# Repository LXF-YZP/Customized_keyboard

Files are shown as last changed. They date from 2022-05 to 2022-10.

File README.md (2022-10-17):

### GPL3协议
### 项目所有文件禁止商用，旨在进行客制化键盘的交流与分享；

## 键盘简单说明

键盘主控使用的是atmega32u4-mu，这里解释一下为什么使用这个芯片，因为最开始画pcb的只会画32u4-au和32u4-mu，其中32u4-mu便宜所以选的这个。
至于更便宜的apm32芯片，仿照的stm32芯片画了一个apm32的pcb图，用于制作pad，刚打样还没有制作完成。对于小配列的键盘也可以使用32u2芯片，比如hhkb或者pad都是可以的，因为32U2相对与32u4便宜；
客制化键盘制作，pcb单模无灯，外壳树脂打印。

更新完qmk固件之后，支持 VIA 实时改键，全键无冲。

+ 目前40配列和hhkb兼容配列的固件还没有编写,pcb也还没有验证,建议等我验证之后再使用；

## 项目分支
>+ master分支： 该分支是田字68的键盘数据。
>+ alice分支：  该分支是Alice配列键盘数据。
>+ hhkb分支：该分支是hhkb配列键盘数据。  
>+ forty_arrangement分支：该分支是40配列键盘数据。  
>+ keypad_frame分支： 键盘支架。 
>+ pad分支： 数字小键盘配列数据。 
>+ seventy_three_arrangement：该分支为73配列键盘数据。
>+ sixty_eight_vim：该分支是68配列键盘数据。（方向键在最下面一排）  

## 目录结构：  
>+ bom 元器件表  
>+ case 外壳图纸  
>+ config 固件文件,支持via改键，解压kafka.zip之后，直接放到qmk的keyboards目录下就可以编译生成hex文件，或者直接使用文件夹中的hex文件  
>+ gerber 制作pcb要上传到立创的压缩文件  
>+ location_plate 配列文件  
>+ pcb pcb原理图  
>+ photo 键盘渲染图，实物图  
>+ screw 螺丝  
>+ acrylic_shell 亚克力外壳图纸

## PCB说明
>>田字68pcb文件中只有无灯无开槽的是适配了3D打印外壳的；田字68的其他pcb还没有适配外壳，其实适配外壳也很简单，无灯的pcb直接修改一下外壳的type-c口即可，有灯的pcb需要在方向键上方开一个适当大小的铭牌口即可。最后解释一下为什么田字68要画这么多pcb的原因，有以下几个原因，pcb开槽和不开槽在手感上有很大差别的，开槽的会更加软弹，不开槽的手感会偏硬一点，gasket结构配上开槽pcb会更加软弹，至于pcb横开槽和全开槽在手感方面也有一点区别，所以制作了多个pcb，本人对轴灯无感，一是光污染（尤其晚上关灯之后），二是画pcb电路图很麻烦（画过一次再也不想画了，玩亚克力的可能会喜欢轴灯），但是本人对氛围灯很有好感，所以有开槽的pcb都有氛围灯。

## 配列图

##### 68配列
+ master分支的68配列如下图所示：
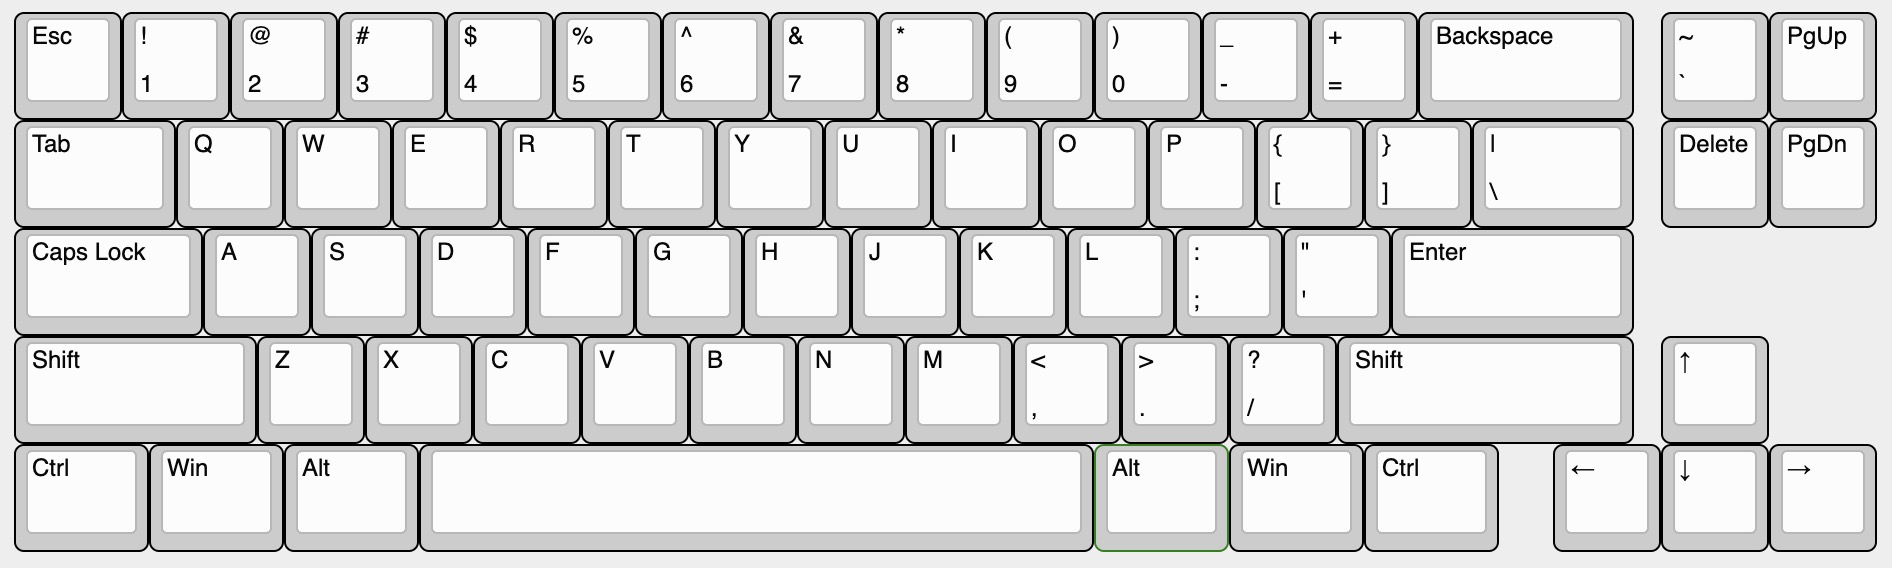
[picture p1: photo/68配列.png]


+ 下列68配列为个人的一些改动：
该配列的配套pcb和外壳还未画好，不过后期都会更新好；
七月三十号pcb外壳已更新，亚克力外壳的准备文件也已更新，亚克力外壳就不再画完整的了，可以在我更新的准备文件基础上进行修改。现在只有固件是没有更新了。如果后续我单板的话，回去更新固件，或者你单板了，可以找我要固件；
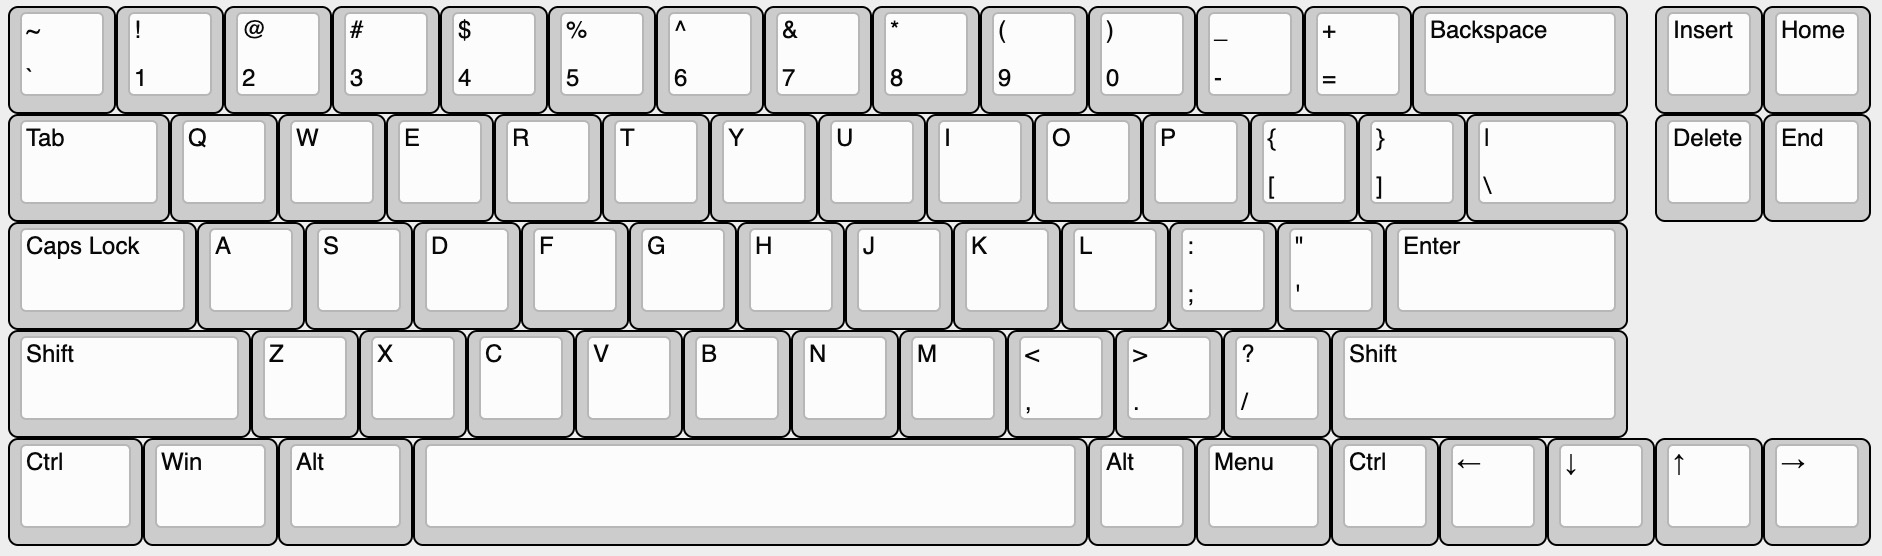
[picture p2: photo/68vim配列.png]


##### hhkb配列
+ hhkb分支的配列如下图：
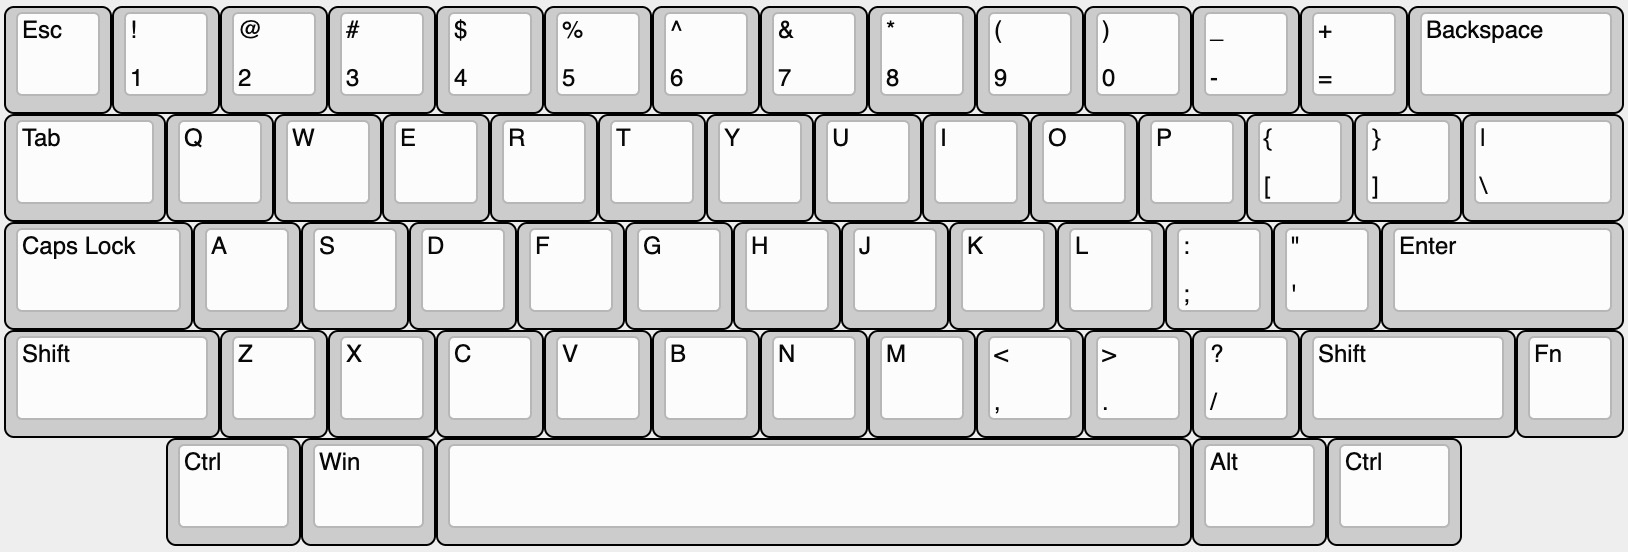
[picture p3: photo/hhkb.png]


+ 下列类hhkb配列为个人的一些改动：
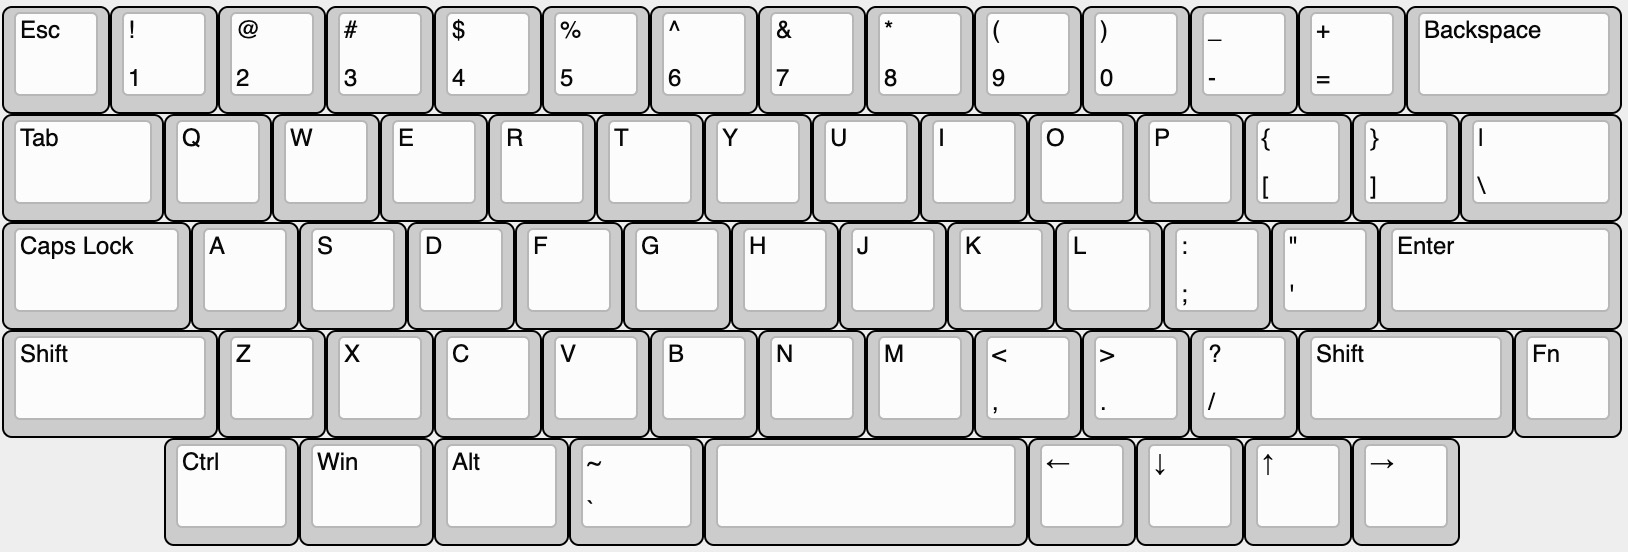
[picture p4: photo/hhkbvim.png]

>> 以上两个配列共用一套pcb和外壳而且已经画好上传到相关文件夹中；pcb是包含两个pcb的gerber文件的，一个是未开槽的pcb只是类hhkb配列的；一个是已经开槽的pcb，这个pcb就是上面说的兼容两个配列的pcb，而且是分离小板的；

##### Alice配列
+ 下面配列是Alice配列：
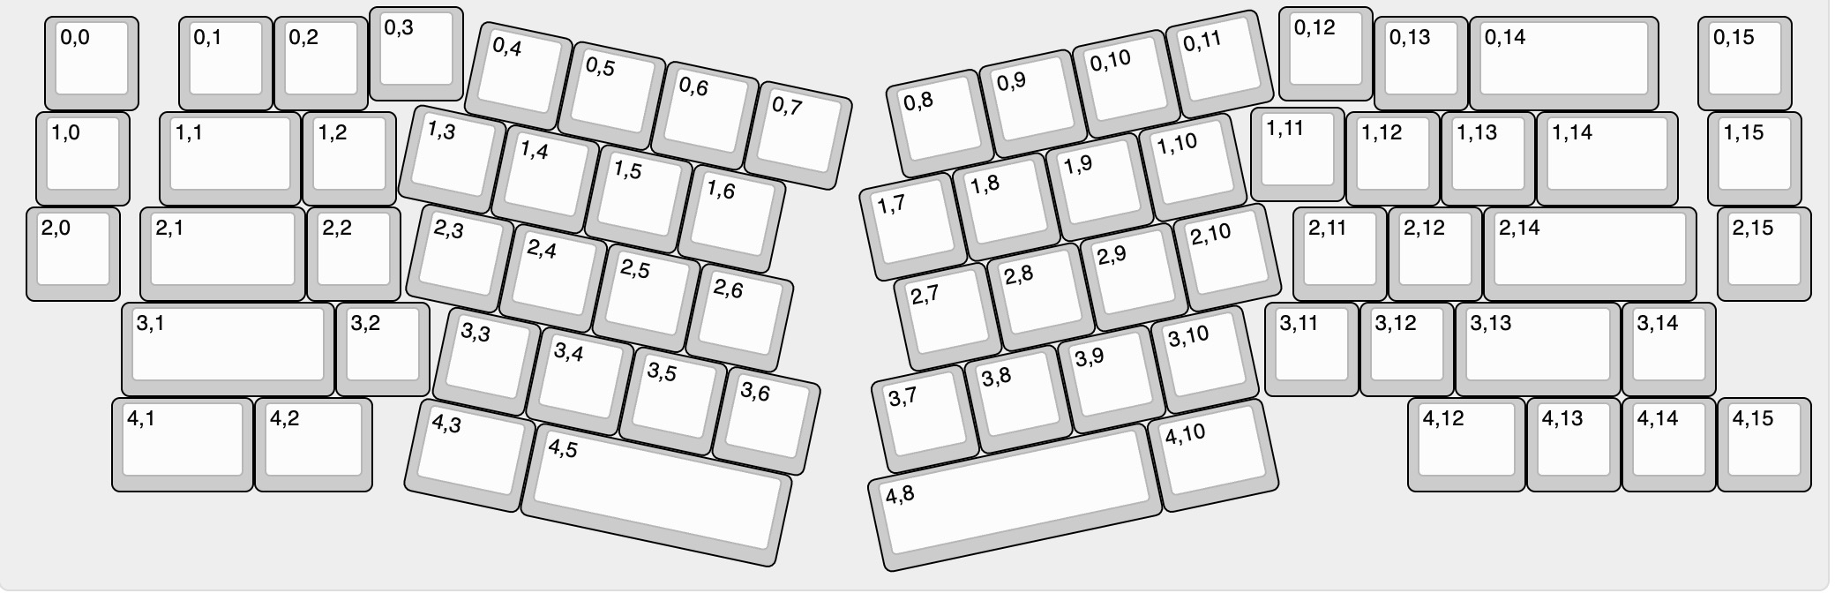
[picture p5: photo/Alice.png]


##### 40配列

+ 40配列如下图
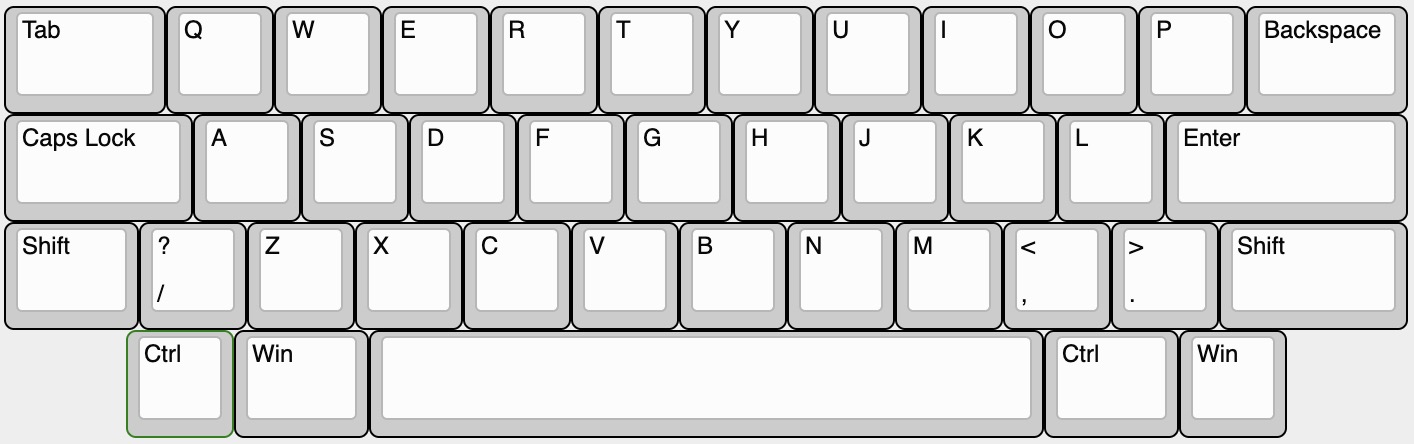
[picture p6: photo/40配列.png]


+ 下列40配列为个人的一些改动：
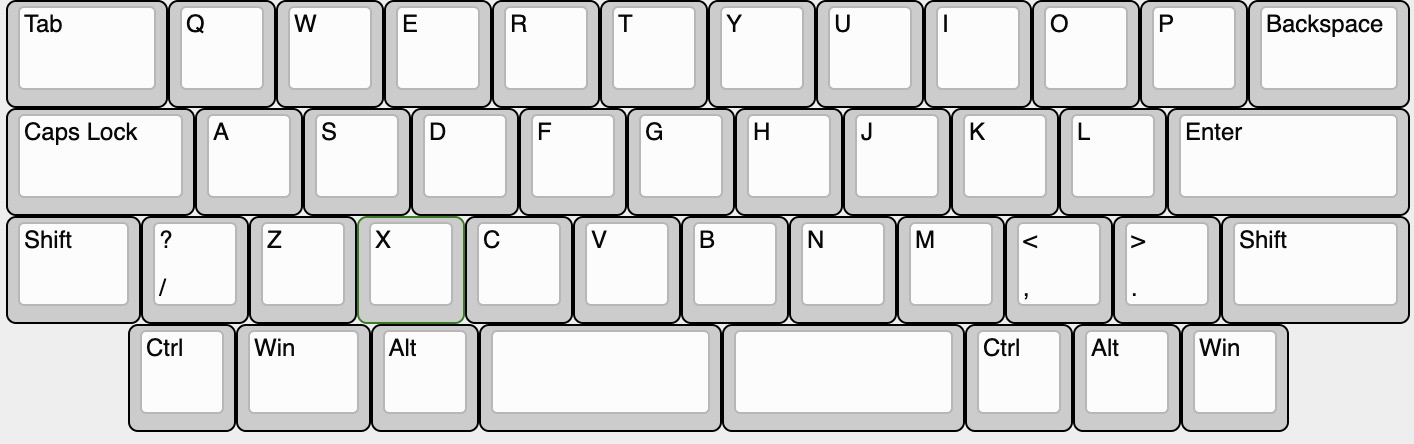
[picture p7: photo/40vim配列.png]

>> 以上两个配列共用一套pcb和外壳而且已经画好上传到相关文件夹中；

##### 73配列

+ 这里多说两句，这个配列最初是在B站看到别人发的一个pcb动态，第一眼感觉很惊艳，所以就自己设计了一款，设计的初衷是送一个朋友的，所以pcb设计的时候走线规整了很多，看着还是比较好看的，由于自己打板子的时候没有选择沉金，所以走线得仔细看才能看出好不好看，要是用沉金的话，就可以把走线都体现出来了，奈何沉金太贵了，要是开团的话选沉金还是不错的。pcb不会开源，该配列主要送朋友的；

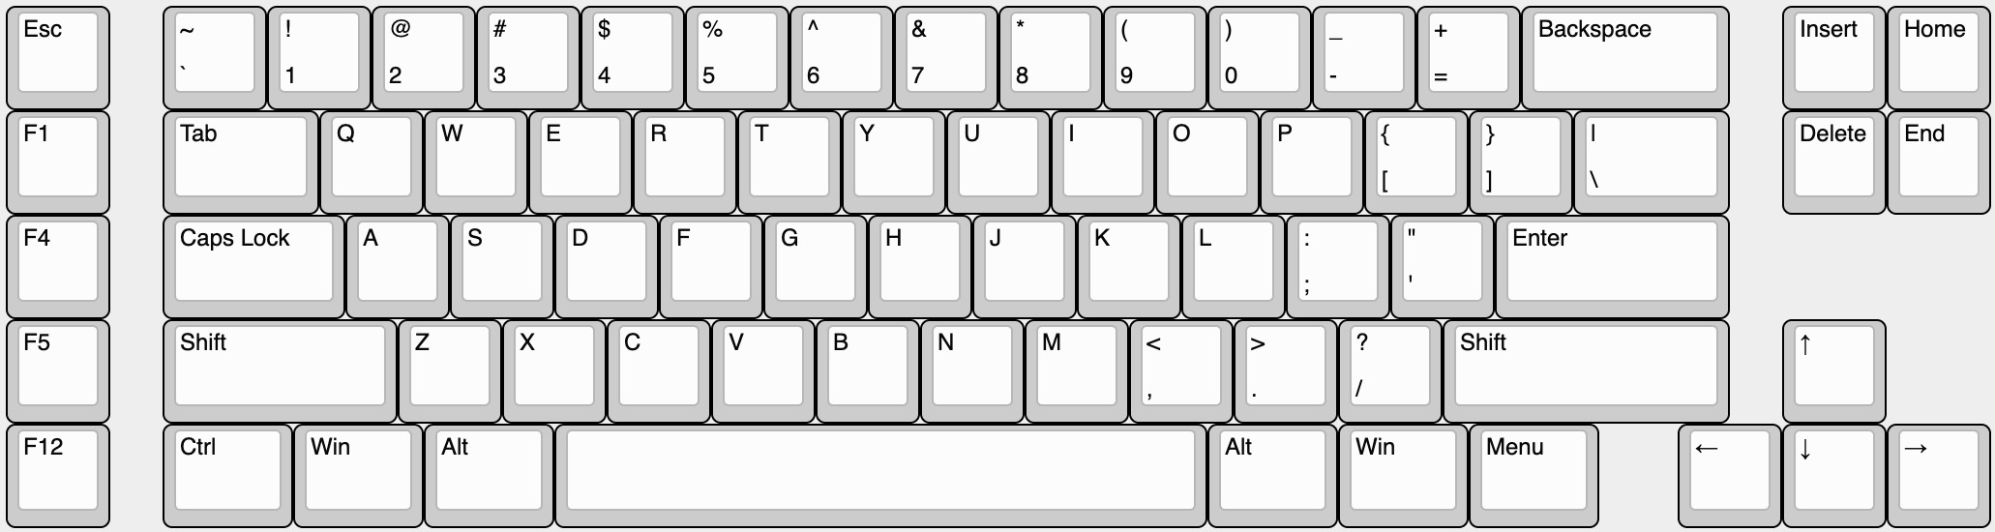
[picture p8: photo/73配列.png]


>> 这个配列开源的pcb和外壳还有固件都是自己最初设计的一版，但是外壳不会开源，因为送朋友的外壳有很多是她自己喜欢的一些元素，所以不开源外壳。但是我有时间会再设计一款外壳。73配列带底灯版本外壳已更新，相关文件后缀带有底灯字样。

田字68全开槽不带分离小板的外壳已经更新，在case文件夹里面的case/田字68底壳.stl文件，其他部分的stl文件是通用的；固件在config/tiankafka_via.hex, via文件在config/tian_kafka_via.json

##### pad

+ pad如下图

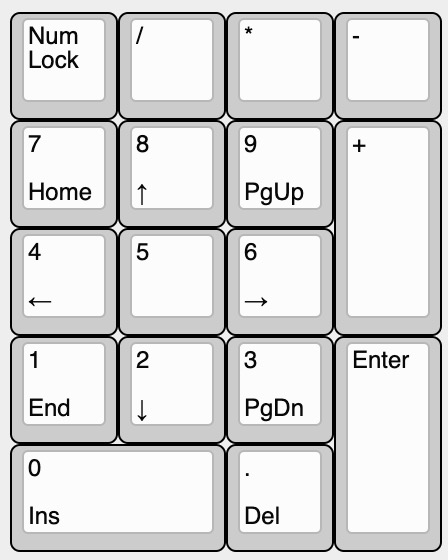
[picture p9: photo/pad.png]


pad使用的芯片为stm32f103,可以使用apm替代，该pad为了验证芯片电路图是否使用正确所画，当前状态为未打板，建议等我打板验证之后再使用。

##### 75配列

+ 75配列如下图

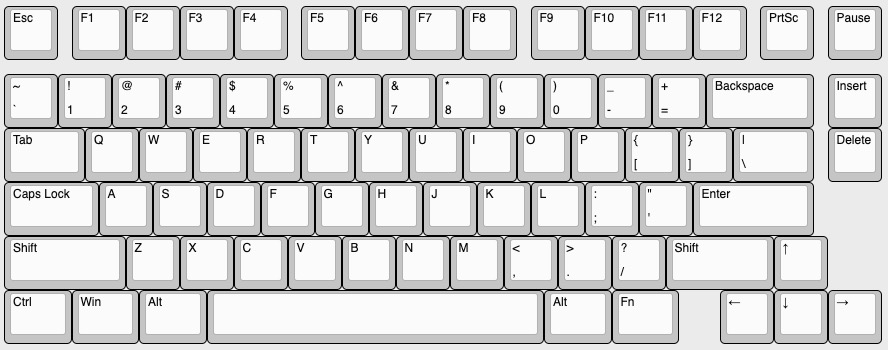
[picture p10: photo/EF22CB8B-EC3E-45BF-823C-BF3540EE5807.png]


75配列使用的芯片为stm32f103,可以使用apm替代，当前pcb还未打板验证，亚克力外壳还没制作，3D打印外壳也还未制作。

+ 79配列如下图

![image]()
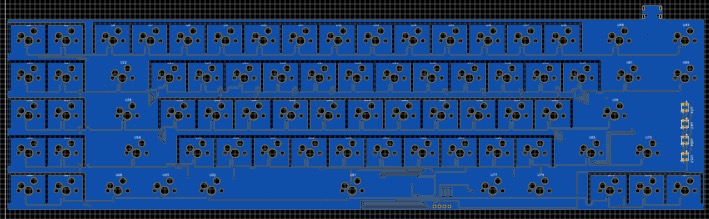
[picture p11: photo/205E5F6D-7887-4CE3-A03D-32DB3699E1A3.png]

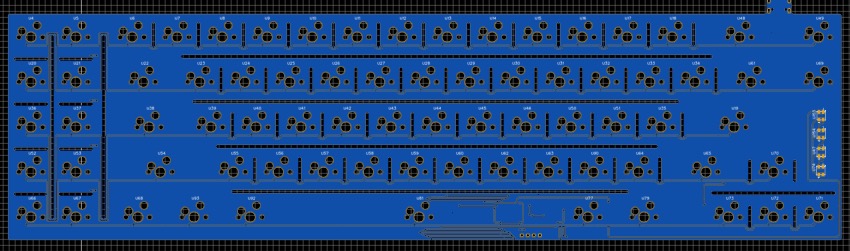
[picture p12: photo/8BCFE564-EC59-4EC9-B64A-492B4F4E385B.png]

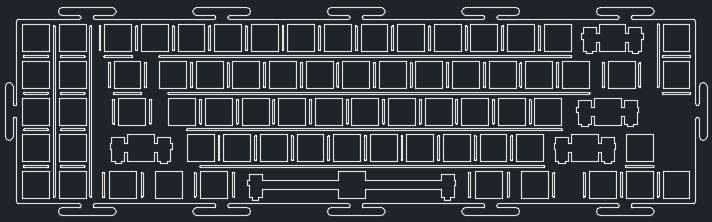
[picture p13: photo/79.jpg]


79配列使用的芯片为stm32f103,可以使用apm替代，pcb有全开槽也有横开槽，当前pcb还未打板验证，亚克力外壳还没制作，3D打印外壳也还未制作。

## 其他配列的pcb图纸有时间再上传吧，其他配列的pcb也有横开槽和全开槽的，部分pcb有竖开槽的。

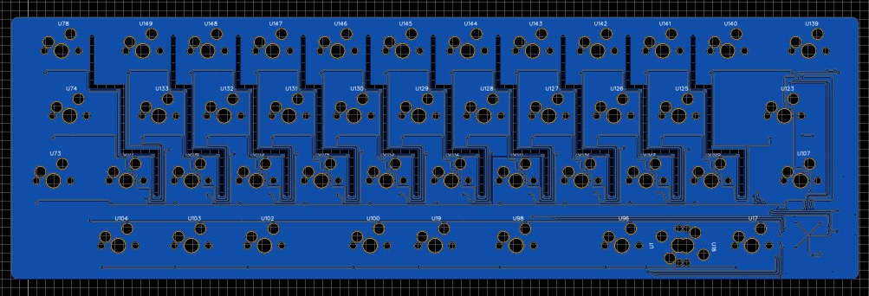
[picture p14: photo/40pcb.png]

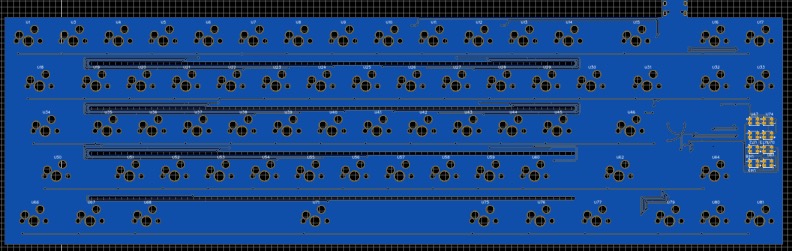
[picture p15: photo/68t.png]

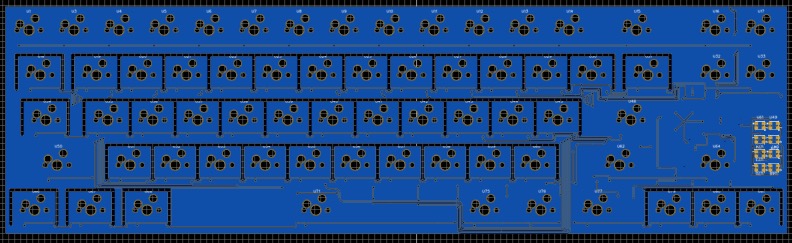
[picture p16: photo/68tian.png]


暂时未适配外壳

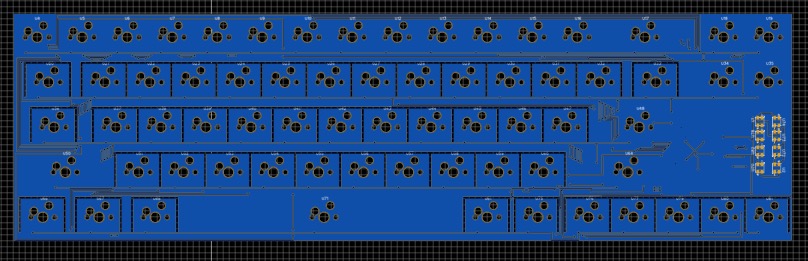
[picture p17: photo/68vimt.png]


暂时未适配外壳

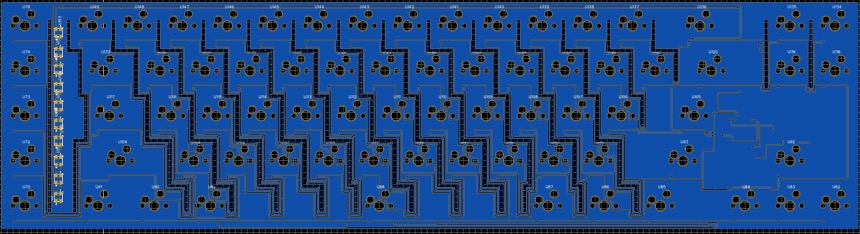
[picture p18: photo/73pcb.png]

该73配列pcb不会开源；

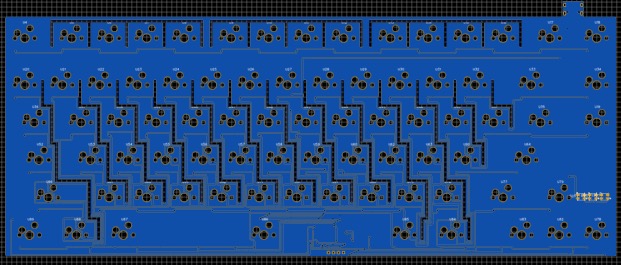
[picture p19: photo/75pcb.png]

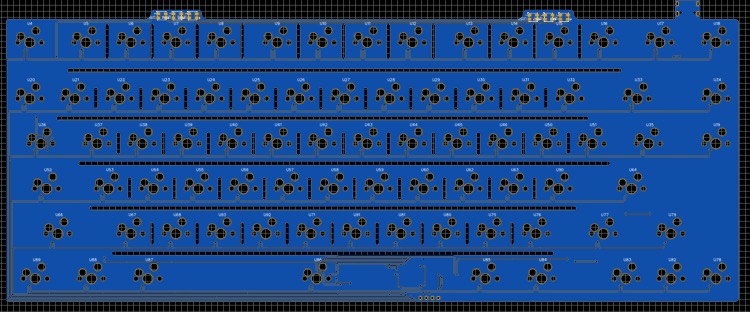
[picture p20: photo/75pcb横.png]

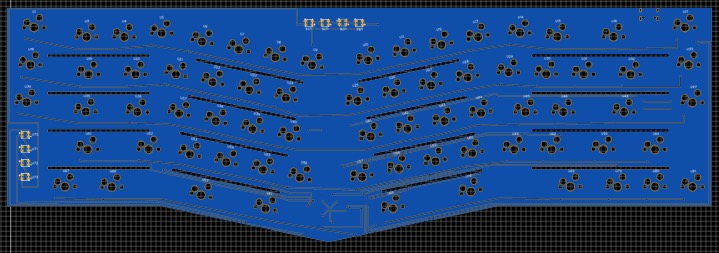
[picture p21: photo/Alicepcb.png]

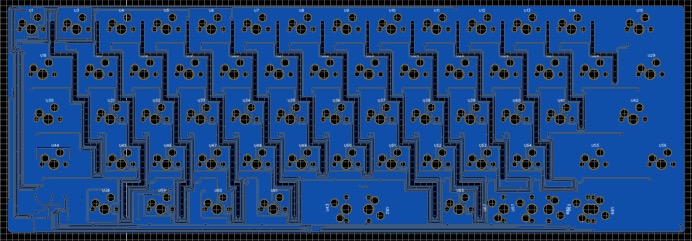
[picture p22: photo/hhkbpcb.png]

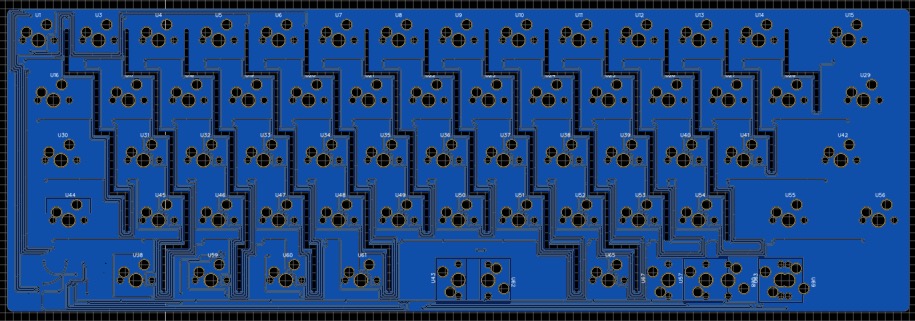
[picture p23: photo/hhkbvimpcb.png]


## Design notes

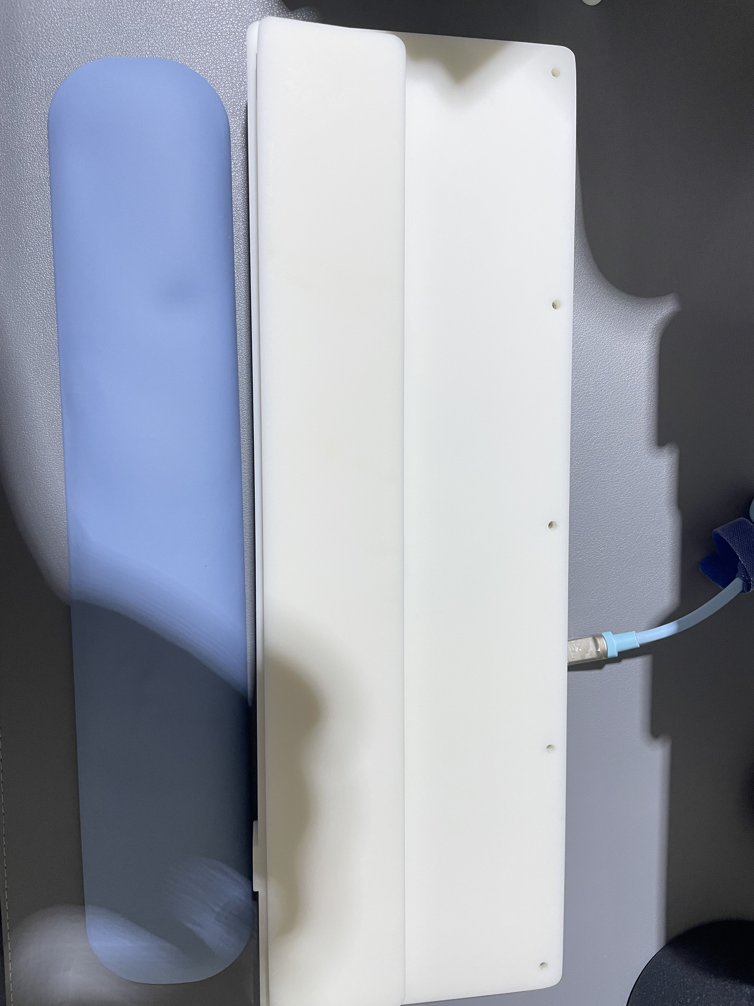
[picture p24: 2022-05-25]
photo/DBA4A1ACDF9258B40D42B9F581A96AAB.png

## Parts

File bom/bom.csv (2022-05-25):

ID | Name | Designator | Footprint | Quantity | Manufacturer Part | Manufacturer | Supplier | Supplier Part | Price | 3DModel
1 | 20pF | C1,C2 | C0805 | 2 | VJ0805D200JLAAJ | VISHAY(威世) | LCSC | C2310327 | 1.3843 | C0805_L2.0-W1.3-H1.3
2 | 1uF | C3 | C0805 | 1 | CL21B105KBFNNNE | SAMSUNG | LCSC | C28323 | 0.0537 | C0805_L2.0-W1.3-H1.3
3 | 100nF | C4,C5,C6,C7 | C0805 | 4 | 0805B104J500NT | FH | LCSC | C29926 | 0.0694 | C0805_L2.0-W1.3-H1.3
4 | 470nF | C8 | C0805 | 1 | 0805B474K500NT | FH | LCSC | C49955 | 0.1168 | C0805_L2.0-W1.3-H1.3
5 | Switch3x4x2 | KEY3 | SW-SMD_L4.0-W2.9-LS5.0 | 1 | Switch3x4x2 | ReliaPro | LCSC | C26638 | 0.2557 | SW-SMD_L4.0-W2.9-H2-LS5.0
6 | 22 | R4,R6 | R0805 | 2 | RC0805FR-0722RL | YAGEO | LCSC | C107702 | 0.0159 | R0805_L2.0-W1.3-H0.6
7 | 10K | R9,R10 | R0805 | 2 | RC0805FR-0710KL | YAGEO | LCSC | C84376 | 0.0154 | R0805_L2.0-W1.3-H0.6
8 | ATMEGA32U4-MU | U2 | VQFN-44_L7.0-W7.0-P0.50-BL-EP5.2 | 1 | ATMEGA32U4-MU | MICROCHIP | LCSC | C112161 | 71.43 | VQFN-44_L7.0-W7.0-H1.0-P0.50
9 | TYPE-C-31-M-12 | USBC2 | USB-C_SMD-TYPE-C-31-M-12 | 1 | TYPE-C-31-M-12 | Rectangular Connectors - Contacts | LCSC | C165948 | 1.5165 | USB-C_SMD-TYPE-C-31-M-12
10 | 16MHz | X3 | OSC-SMD_2P-L5.0-W3.2 | 1 | XSHEELNANF-16MHZ | TAITIEN Elec | LCSC | C242221 | 2.39 | OSC-SMD-2P_L5.0-W3.2-H1.4
11 | 1N4148W T4 | D1,D2,D3,D4,D5,D6,D7,D8,D9,D10,D11,D12,D13,D14,D15,D16,D17,D18,D19,D20,D21,D22,D23,D24,D25,D26,D27,D28,D29,D30,D31,D32,D33,D34,D35,D36,D37,D38,D39,D40,D41,D42,D43,D44,D45,D49,D50,D51,D52,D53,D54,D55,D56,D57,D58,D59,D61,D63,D65,D66,D67,D70,D74,D75,D76,D78,D79,D80 | SOD-123_L2.8-W1.8-LS3.7-RD | 68 | 1N4148W T4 | CJ | LCSC | C2099 | 0.0844 | SOD-123_L2.8-W1.8-LS3.7-RD
12 | 两用轴座无灯 | U1,U3,U4,U5,U6,U7,U8,U9,U10,U11,U12,U13,U14,U15,U16,U17,U18,U19,U20,U21,U22,U23,U24,U25,U26,U27,U28,U29,U30,U31,U32,U33,U34,U35,U36,U37,U38,U39,U40,U41,U42,U43,U44,U45,U46,U50,U51,U52,U53,U54,U55,U56,U57,U58,U59,U60,U62,U64,U66,U67,U68,U71,U75,U76,U77,U79,U80,U81 | 两用轴座无灯 | 68

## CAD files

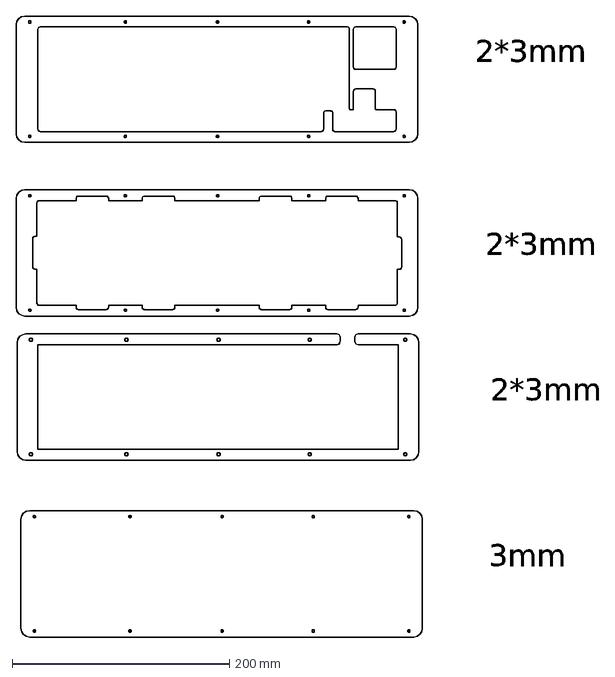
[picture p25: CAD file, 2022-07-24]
acrylic_shell/亚克力外壳.dxf
2*3mm
3mm

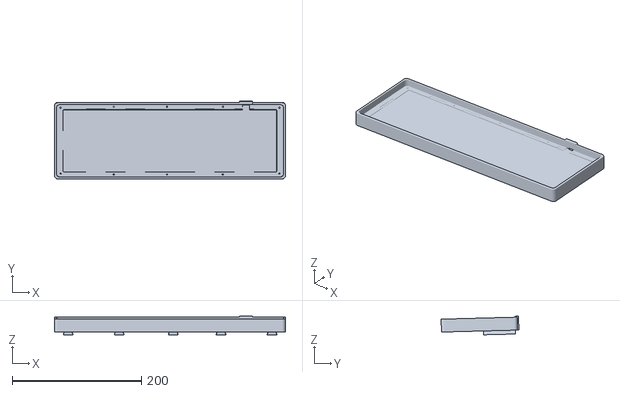
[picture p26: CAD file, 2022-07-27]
case/田字68底壳.stl
357.6 x 120.5 x 28.9

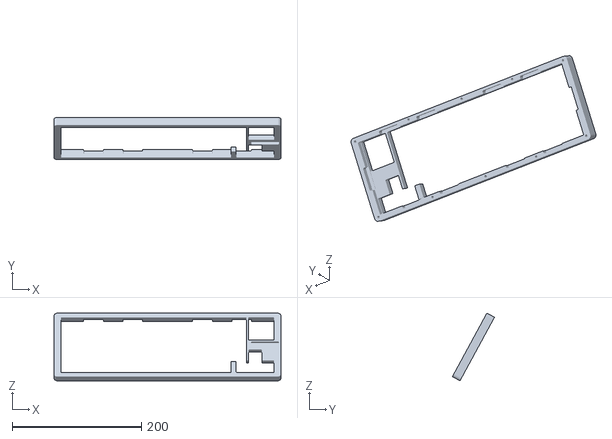
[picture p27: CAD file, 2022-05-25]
case/上壳.stl
351.6 x 65.1 x 104.7

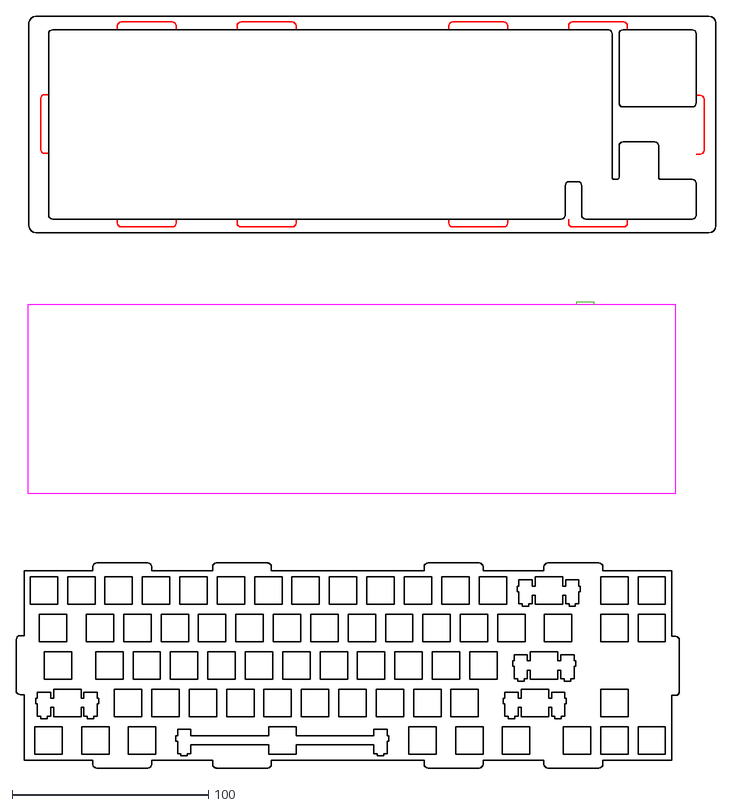
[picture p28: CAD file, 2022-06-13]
location_plate/定位板.dxf
356.3 x 383.0

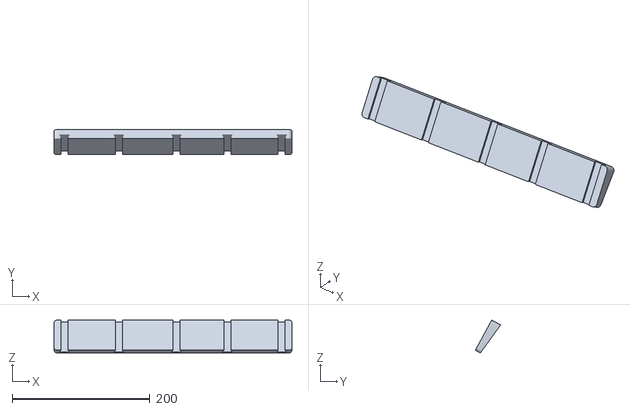
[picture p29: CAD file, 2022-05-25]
case/配重.stl
346.0 x 36.9 x 48.0

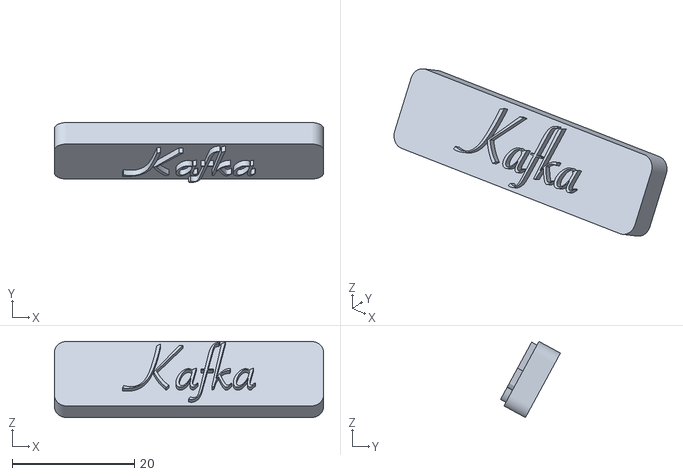
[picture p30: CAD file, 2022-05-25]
case/铭牌.stl
44.0 x 9.80 x 12.5

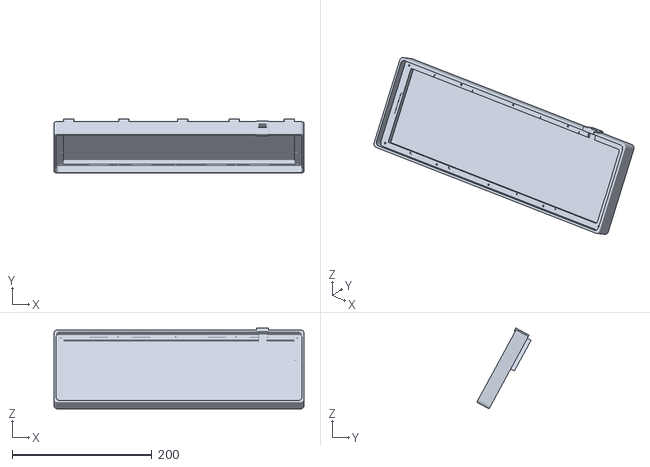
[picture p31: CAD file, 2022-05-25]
case/底壳.stl
357.6 x 77.5 x 115.5

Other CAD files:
location_plate/定位板基板.dwg

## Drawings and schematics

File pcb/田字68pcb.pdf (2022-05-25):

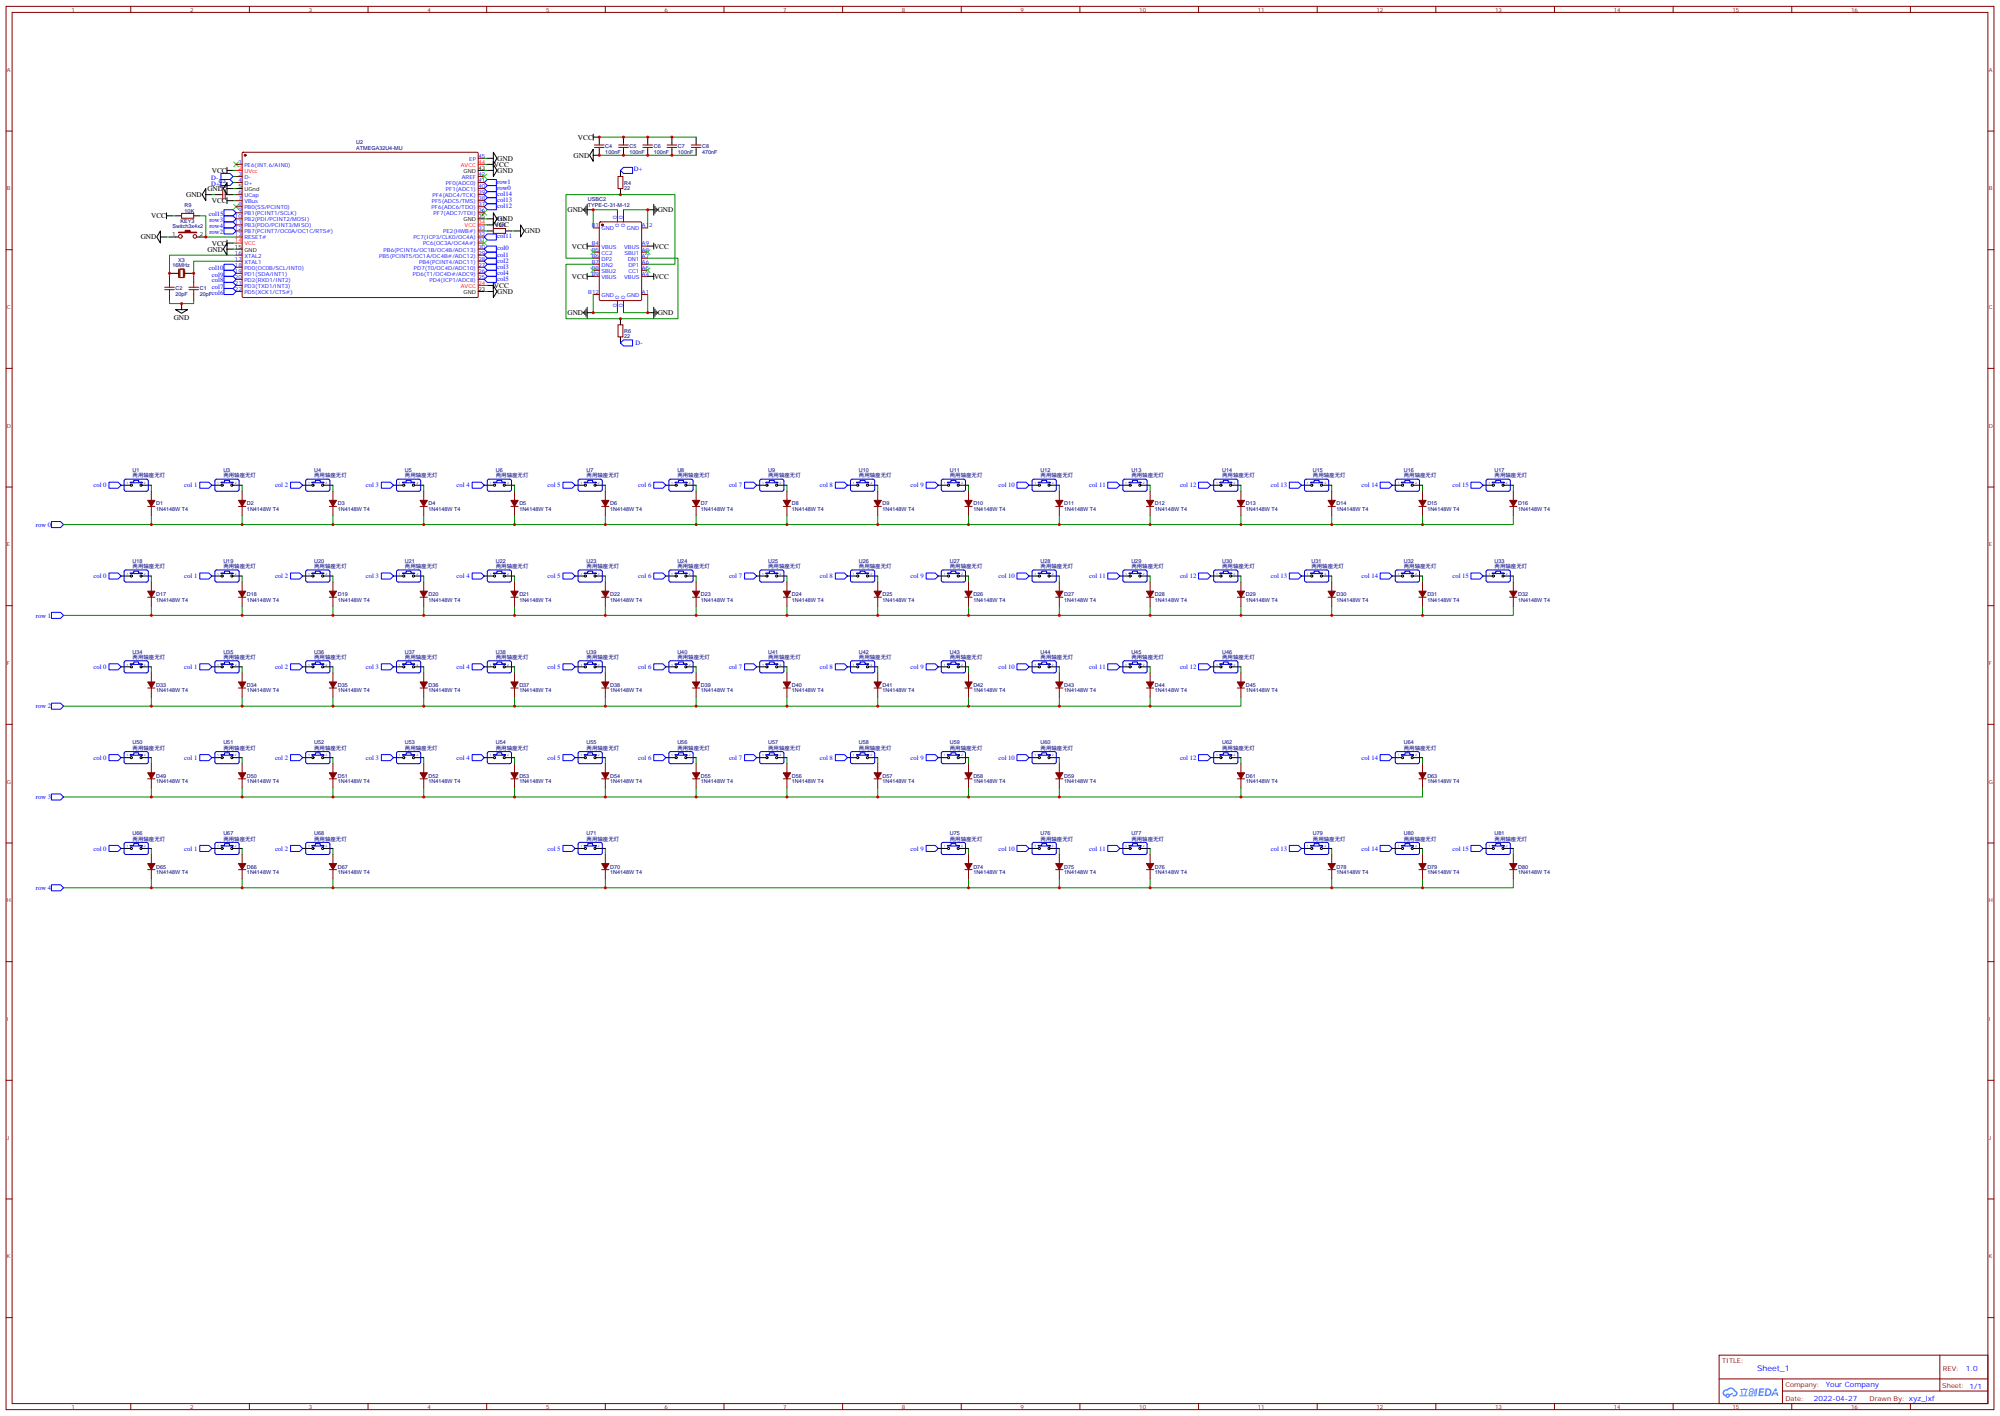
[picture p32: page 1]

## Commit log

2022-05-25 客制化键盘
2022-05-25 删除.un后缀文件
2022-05-25 添加必要文件
    [bom.csv, 上壳.stl, 底壳.stl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]
2022-05-25 添加pcb定位板
    [定位板pcb.dxf, 定位板基板.dwg]
2022-05-25 添加简介
2022-05-25 添加配置
2022-05-26 目录介绍
2022-06-01 master分支
2022-06-01 删除无用文件
2022-06-01 “更新简介”
2022-06-06 添加开槽基板
    [定位板基板.dwg]
2022-06-11 更新开槽pcb
    [定位板基板.dwg]
2022-06-13 更新开槽pcb和定位板
    [定位板pcb.dxf, 定位板基板.dwg]
2022-06-15 更新定位板细节
    [定位板.dxf, 定位板基板.dwg]
2022-06-24 更新键盘固件，支持via改键
2022-06-24 更新说明文档
    [定位板基板.dwg]
2022-06-24 更新固件文件
2022-06-24 更新田字68亚克力外壳
    [亚克力外壳.dxf]
2022-06-24 修改某些内容
2022-06-24 更新md文件
2022-06-24 更新亚克力外壳
2022-06-24 更新亚克力图纸
2022-06-25 更新带分离小板pcb以及分离小板
2022-06-25 更新文档说明
2022-06-25 更新文档
2022-06-26 更新via配置
2022-07-24 更新68配列图
    [亚克力外壳.dxf]
2022-07-25 更新配列图片
2022-07-27 更新田字68全开槽外壳
    [田字68底壳.stl]
2022-07-27 更新田字68全开槽pcb固件
2022-07-29 更新配列
2022-07-31 更新pad配列
2022-08-02 更新相关文件说明
2022-08-03 更新键盘文件说明
2022-08-05 更新键盘最新信息
2022-08-10 更新75配列
2022-08-11 更新readme文件
2022-08-25 更新md文件说明
2022-09-08 更新md
2022-09-08 更新配列图纸
2022-09-08 更新pcb图纸
2022-09-08 更新pcb截图
2022-09-09 更新定位板图片
2022-09-09 更新定位板图纸
